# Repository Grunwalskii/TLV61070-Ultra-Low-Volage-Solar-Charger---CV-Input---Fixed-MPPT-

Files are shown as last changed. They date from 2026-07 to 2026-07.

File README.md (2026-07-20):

# TLV61070 Ultra-Low Voltage Solar Harvester & Booster

A low-cost, ultra-low voltage energy harvesting and management circuit built around the **TI TLV61070** synchronous boost regulator. By incorporating a precision external operational amplifier loop (`MCP6001T`) and an adjustable voltage reference (`TL432`), this design implements a reliable Constant Voltage (CV) input control scheme ("Fixed MPPT") to maximize solar extraction without collapsing low-power panels.

---
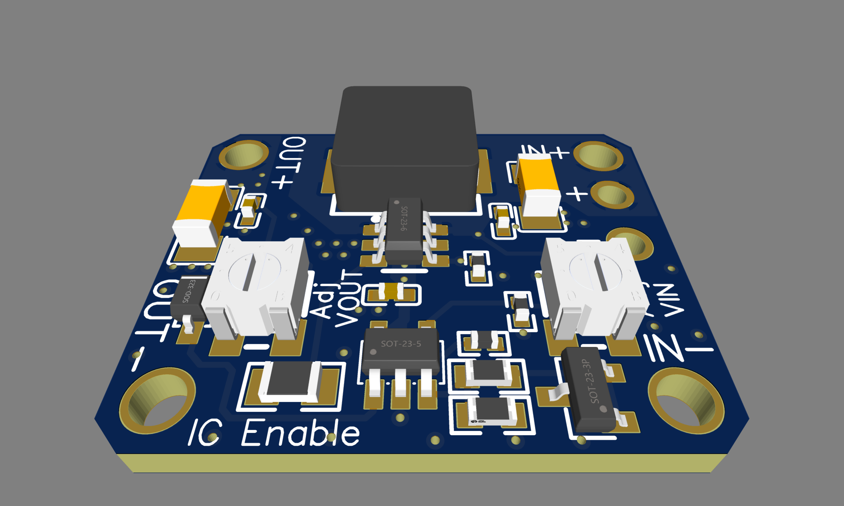
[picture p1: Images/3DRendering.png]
Rendering

## Technical Specifications & Features

* **Wide Input Range:** Handles `0.5V to 5.5V` (Absolute max: `7.0V`).
* **Ultra-Low Start-up:** Triggers at `1.3V` and operates down to `0.5V` once running.
* **Flexible Output Range:** Programmable between `2.2V and 5.5V` (with built-in `5.7V` Output Overvoltage Protection).
* **True Disconnect Shutdown:** Completely disconnects the chip from input power during shutdown, dropping current draw to just `0.1 µA`.
* **Integrated Safety:** Features integrated short-circuit protection and thermal shutdown.

### Quiescent Current Breakdown
* **$V_{in}$ Quiescent Current:** ~`11 µA` (Voltage Divider) + `1 µA` (TLV)
* **$V_{out}$ Quiescent Current:** ~`176 µA` total (`100 µA` Op-amp, `47 µA` Reference, `9 µA` Voltage Divider, `20 µA` TLV).

---

## Real-World Measured Efficiency

The synchronous rectification design delivers excellent power conversion efficiency across typical harvesting and step-up scenarios:

| Input ($V_{in}$) | Output ($V_{out}$) | Output Current ($I_{out}$) | Input Power | Output Power | Efficiency |
| :--- | :--- | :--- | :--- | :--- | :--- |
| **3.6 V** | 5.0 V | 5.0 mA | 26.71 mW | 25.00 mW | **94%** |
| **3.6 V** | 5.0 V | 50.0 mA | 284.00 mW | 250.00 mW | **88%** |
| **1.8 V** | 5.0 V | 50.0 mA | 264.00 mW | 250.00 mW | **94%** |
| **1.8 V** | 4.0 V | 40.0 mA | 172.00 mW | 160.00 mW | **93%** |

## Thermal Test
Input: 1.8V/2A - Output: 4V - TLV Temp: 82c at 24C Room

## Circuit Tuning & Potentiometers

The design features dual adjustment windows via resistor/potentiometer networks to easily dial in your specific solar panel characteristics and target storage voltage:

### 1. Input Side (Fixed MPPT Threshold)
Uses a `47k` resistor base to set the `0.5V` reference point tracking.
* **Minimum (10k):** `0.6V` MPPT lock voltage.
* **Middle (260k):** `3.3V` MPPT lock voltage.
* **Maximum (510k):** `6.0V` MPPT lock voltage.
* *Current draw across the input divider is approximately `11 µA`.*

### 2. Output Side (Target Voltage Configuration)
Uses a `47k` resistor base to match the reference feedback loop.
* **Minimum (100k):** `1.6V` target output.
* **Middle (350k):** `4.3V` target output.
* **Maximum (600k):** `6.9V` target output.
* *Current draw across the output divider is approximately `9 µA`.*

## Support

If you enjoy this project and want to support its development, you can buy me a coffee:



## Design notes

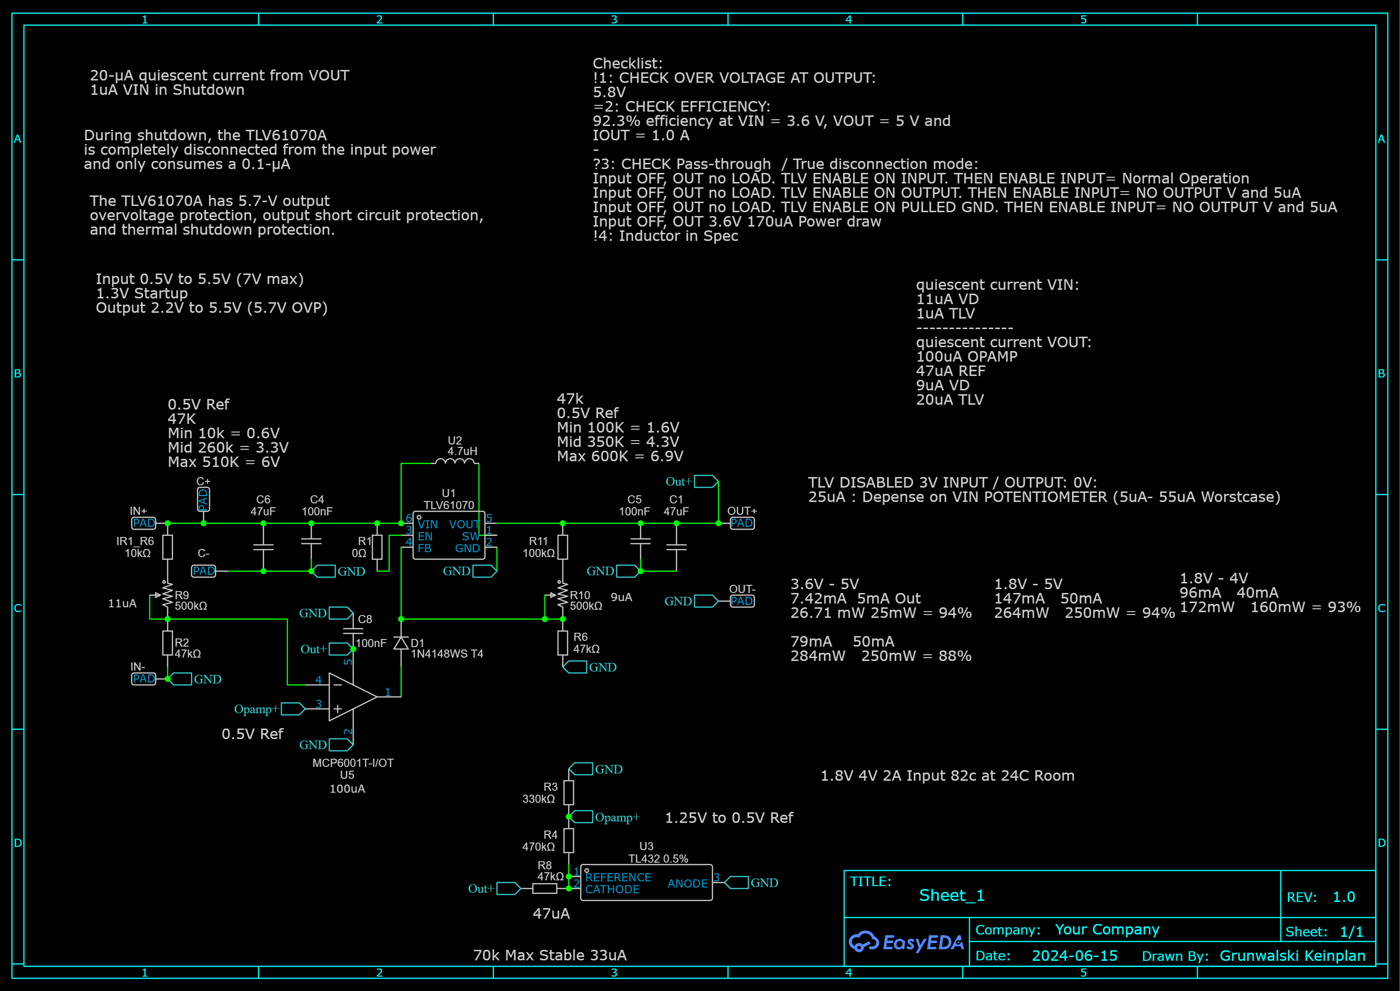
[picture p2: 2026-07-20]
Images/Schematic.png

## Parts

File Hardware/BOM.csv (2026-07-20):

ID | Name | Designator | Footprint | Quantity | Manufacturer Part | Manufacturer | Supplier | Supplier Part | Price
1 | 0Ω | R1 | R0805 | 1 | 0805W8F0000T5E | UNI-ROYAL(厚声) | LCSC | C17477 | 0.011
2 | ThroughHole | OUT-,C+,C-,OUT+,IN+,IN- | THRO_HOLE_FP | 6 |  |  | N/A
3 | 47uF | C1,C6 | C1206 | 2 | CL31A476MPHNNNE | SAMSUNG(三星) | LCSC | C96123 | 0.389
4 | 47kΩ | R8,R2,R6 | R0402 | 3 | 0402WGF4702TCE | UNI-ROYAL(厚声) | LCSC | C25792 | 0.007
5 | 500kΩ | R9,R10 | RES-ADJ-SMD_3313J-1 | 2 | 3313J-1-504E | BOURNS | LCSC | C124628 | 0.899
6 | 100kΩ | R11 | R0402 | 1 | 0402WGF1003TCE | UNI-ROYAL(厚声) | LCSC | C25741 | 0.007
7 | 4.7uH | U2 | IND-SMD_L7.0-W6.6_APH0630 | 1 | APH0630T4R7M | APV(爱普微) | LCSC | C5349705 | 0.072
8 | TL432 0.5% | U3 | SOT-23-3_L2.9-W1.3-P1.90-LS2.4-BR | 1 | TL432 0.5% | UMW(友台半导体) | LCSC | C545558 | 0.047
9 | TLV61070 | U1 | SOT-23-6_L2.9-W1.6-P0.95-LS2.8-BR | 1 | TLV61070ADBVR | TI(德州仪器) | LCSC | C6881375 | 0.245
10 | 10kΩ | IR1_R6 | R0402 | 1 | 0402WGF1002TCE | UNI-ROYAL(厚声) | LCSC | C25744 | 0.009
11 | 100nF | C4,C5,C8 | C0402 | 3 | CL05B104KO5NNNC | SAMSUNG(三星) | LCSC | C1525 | 0.005
12 | 1N4148WS T4 | D1 | SOD-323_L1.8-W1.3-LS2.5-RD | 1 | 1N4148WS | CJ(江苏长电/长晶) | LCSC | C2128 | 0.013
13 | 330kΩ | R3 | R0603 | 1 | 0603WAF3303T5E | UNI-ROYAL(厚声) | LCSC | C23137 | 0.003
14 | 470kΩ | R4 | R0603 | 1 | 0603WAF4703T5E | UNI-ROYAL(厚声) | LCSC | C23178 | 0.013
15 | MCP6001T-I/OT | U5 | SOT-23-5_L3.0-W1.7-P0.95-LS2.8-BR | 1 | MCP6001T-I/OT | MICROCHIP(美国微芯) | LCSC | C116490 | 0.265
